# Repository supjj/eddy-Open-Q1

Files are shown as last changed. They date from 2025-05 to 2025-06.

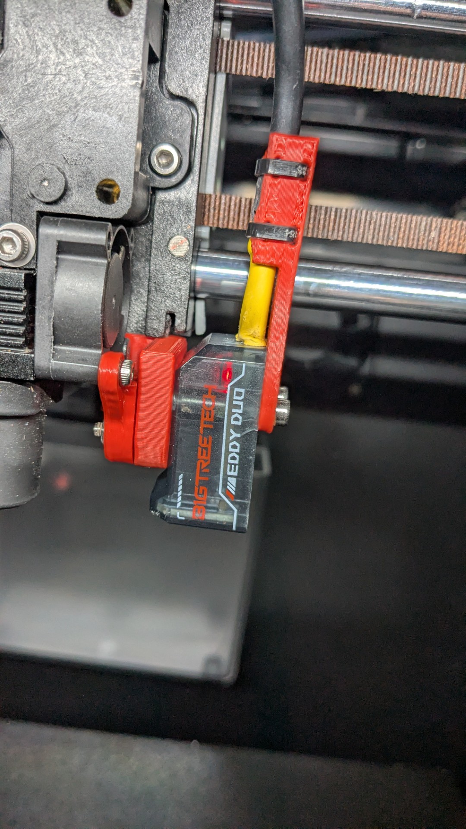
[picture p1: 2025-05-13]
eddy_mount/images/q1_pro_eddy_easyalign4 (Large).jpg

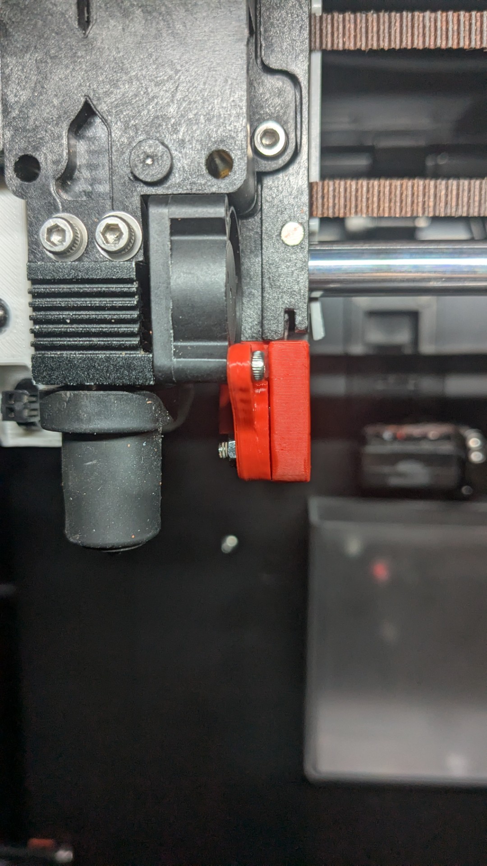
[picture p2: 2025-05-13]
eddy_mount/images/q1_pro_eddy_easyalign3 (Large).jpg

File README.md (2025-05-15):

# eddy-Open-Q1
eddy/eddy-ng configurations for Qidi Open Q1 Pro

Goal: to ease friction when swapping eddy and eddy-ng probe configurations

For use with

https://github.com/frap129/OpenQ1

Additional reference

https://github.com/bigtreetech/Eddy

https://github.com/vvuk/eddy-ng

https://github.com/straga/3d_printer

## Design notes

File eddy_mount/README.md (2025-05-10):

WARNING! It is vital that the 18mm screws that come with the Big Tree Tech Eddy are used with this mount. Longer screws will bottom out (top out in this case) and cause carriage assembly issues when tightened.

Configuration files will need to be tweaked depending on the model that is printed. The configs in this repo are made for the 2mm inset model I am using.

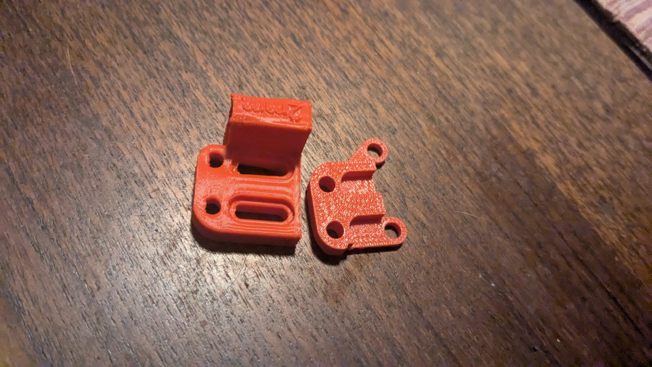
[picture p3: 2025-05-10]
eddy_mount/images/q1_eddy_stable1 (Large).jpg

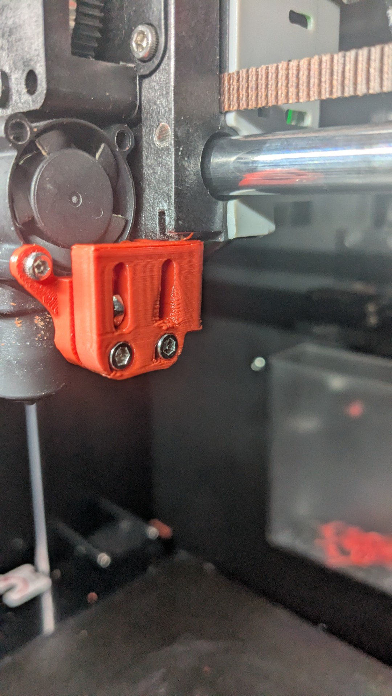
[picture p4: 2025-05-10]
eddy_mount/images/q1_eddy_stable2 (Large).jpg

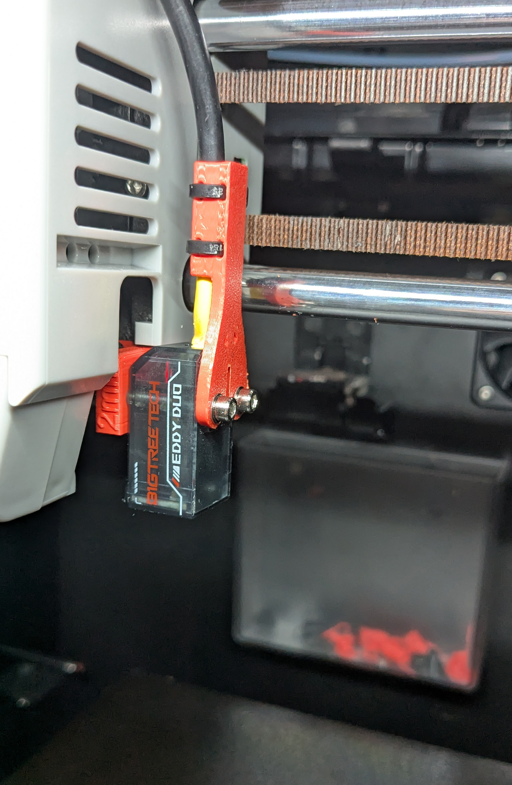
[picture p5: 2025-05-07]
eddy_mount/images/btt_eddy_strain_relief.jpg

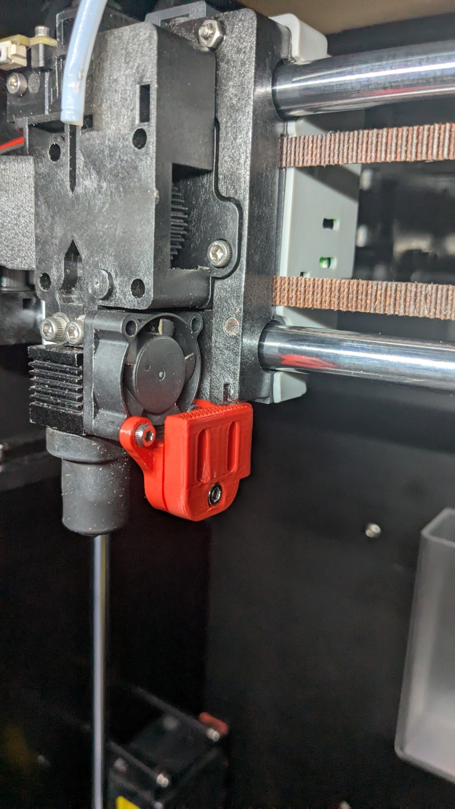
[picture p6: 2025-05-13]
eddy_mount/images/q1_pro_eddy_easyalign2 (Large).jpg

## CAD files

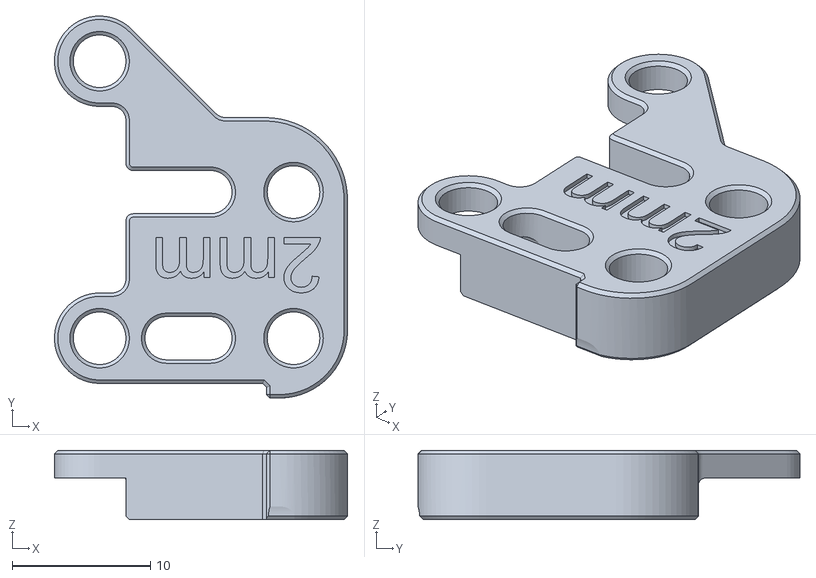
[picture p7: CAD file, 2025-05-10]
eddy_mount/stable_eddy/stl/2mm_full_inset_plate.stl
21.2 x 27.6 x 5.00

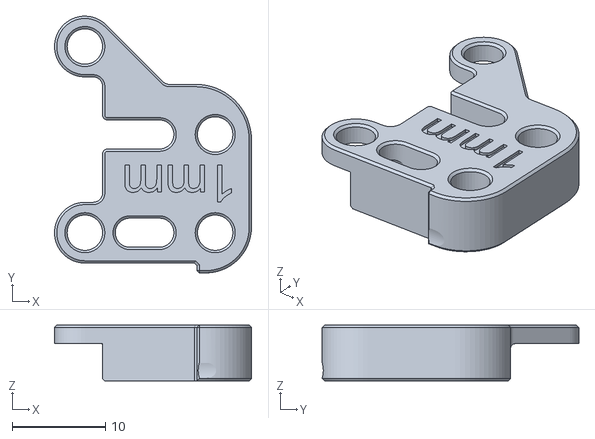
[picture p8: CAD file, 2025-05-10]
eddy_mount/stable_eddy/stl/1mm_full_inset_plate.stl
21.2 x 27.6 x 6.00

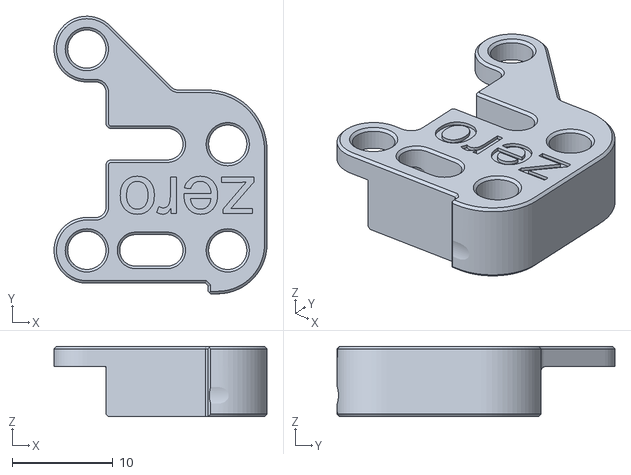
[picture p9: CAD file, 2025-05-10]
eddy_mount/stable_eddy/stl/zero_full_inset_plate.stl
21.2 x 27.6 x 7.00

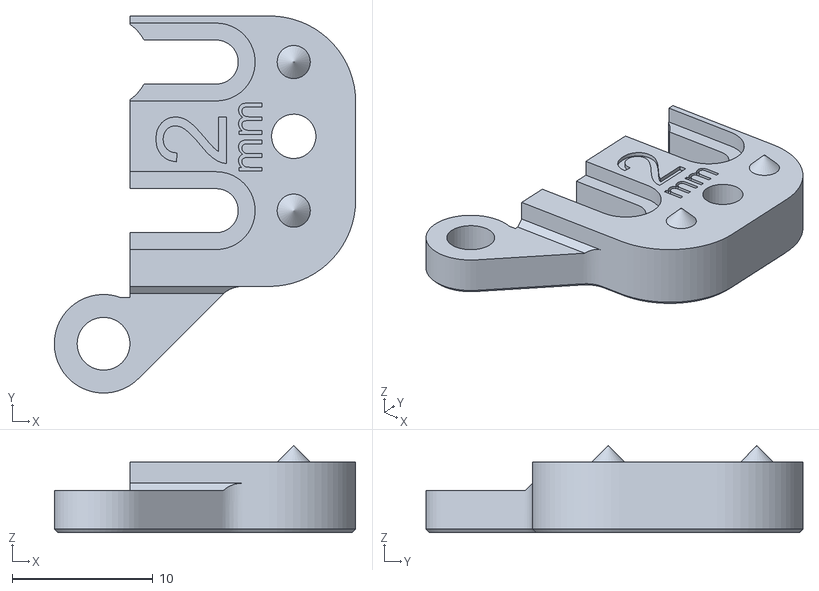
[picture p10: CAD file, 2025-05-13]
eddy_mount/easy_align_stable/2mm_inset_fan_mount.stl
21.4 x 26.8 x 6.18

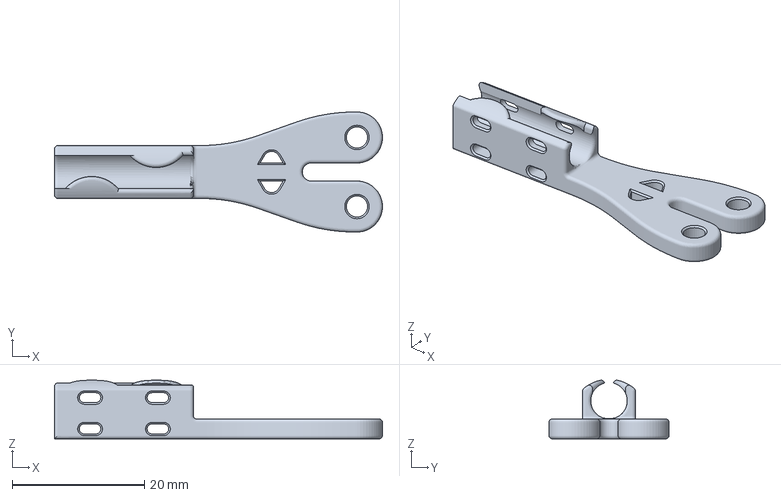
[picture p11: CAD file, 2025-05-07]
eddy_mount/eddy/btt_eddy_strain_relief.3mf
49.6 x 18.1 x 8.87 mm

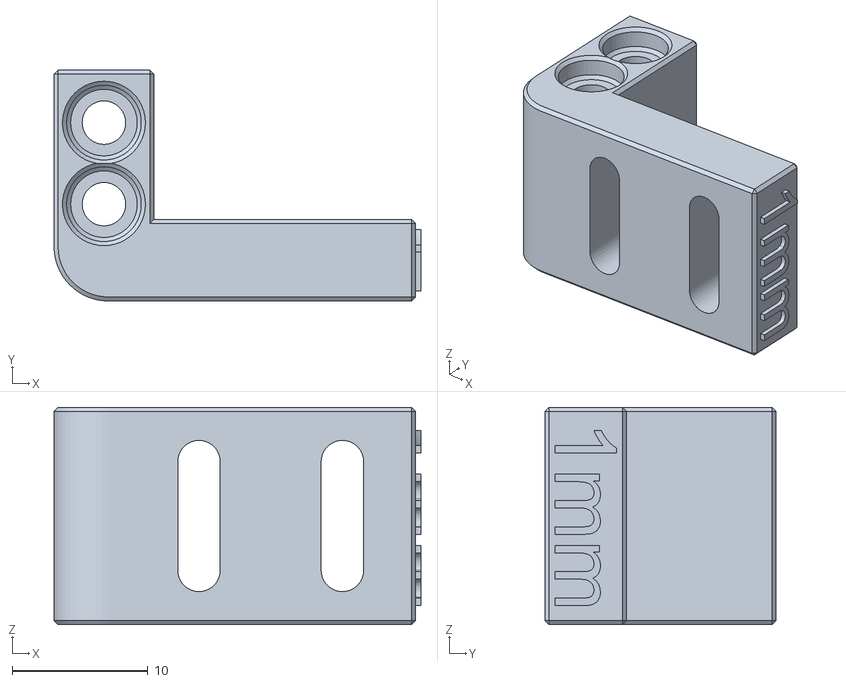
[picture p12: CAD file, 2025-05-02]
eddy_mount/eddy/stl/1mm_inset.stl
27.0 x 17.0 x 16.0

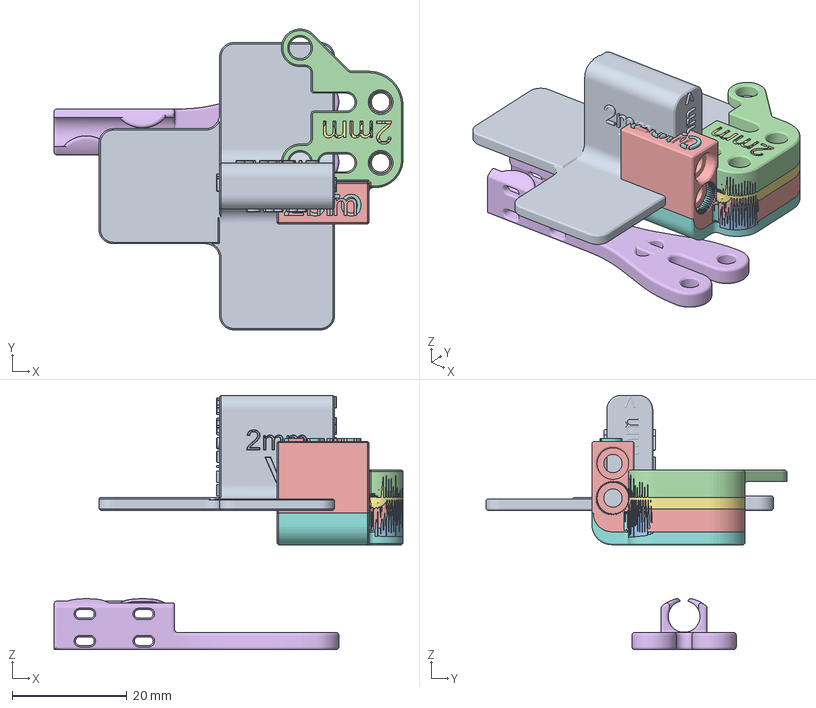
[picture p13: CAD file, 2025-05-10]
eddy_mount/stable_eddy/Q1_Pro_btt_eddy_mount v160.3mf
60.7 x 52.3 x 44.2 mm
calibration_block_20mm
1mm_full_inset_plate
1mm_inset
2mm_full_inset_plate
2mm_inset
strain_relief_stub
zero_full_inset_plate
zero_inset

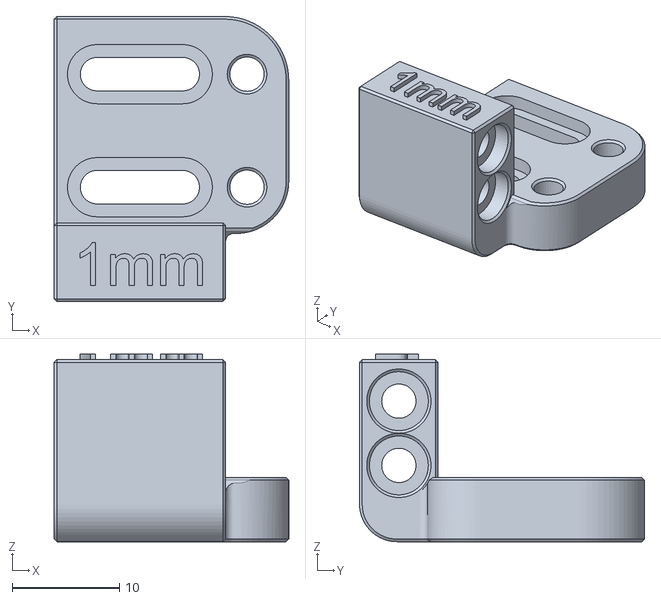
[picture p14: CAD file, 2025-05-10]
eddy_mount/stable_eddy/stl/1mm_inset.stl
21.9 x 26.6 x 17.5

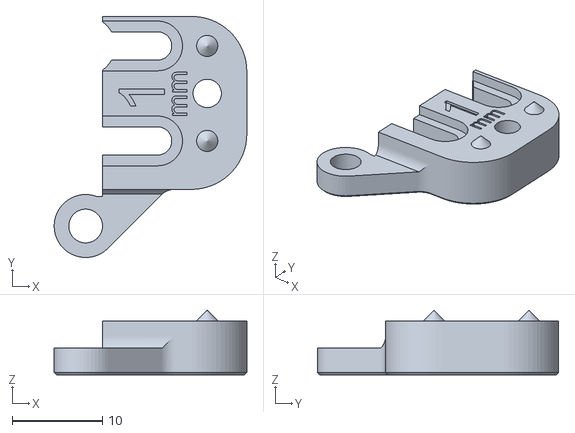
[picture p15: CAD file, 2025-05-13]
eddy_mount/easy_align_stable/1mm_inset_fan_mount.stl
21.4 x 26.8 x 7.18

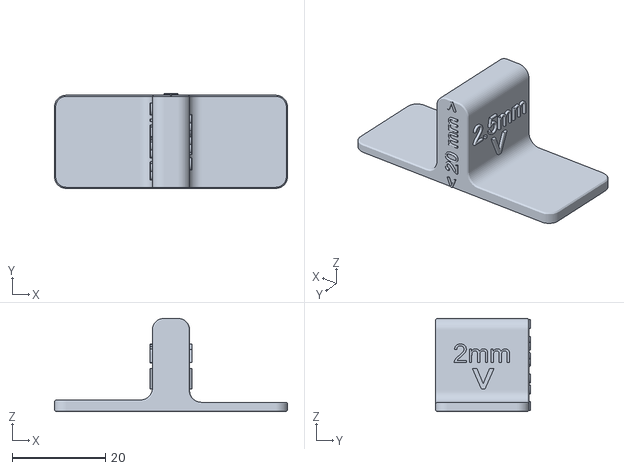
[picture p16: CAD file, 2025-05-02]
eddy_mount/eddy/stl/calibration_block_2mm_20mm_2.5mm.stl
50.0 x 20.3 x 20.0

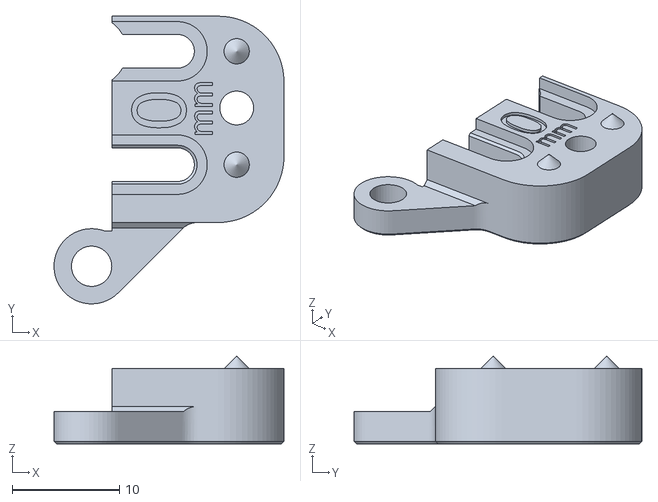
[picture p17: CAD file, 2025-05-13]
eddy_mount/easy_align_stable/zero_inset_fan_mount.stl
21.4 x 26.8 x 8.18

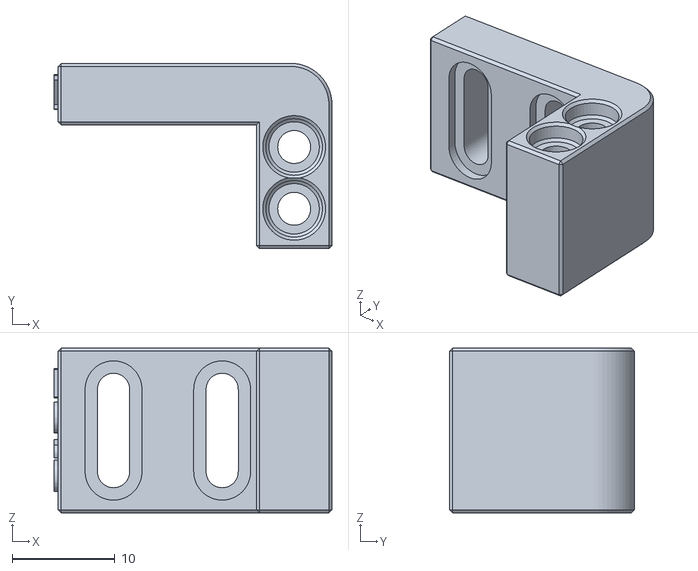
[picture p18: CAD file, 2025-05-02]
eddy_mount/eddy/stl/zero.stl
27.0 x 18.0 x 16.0

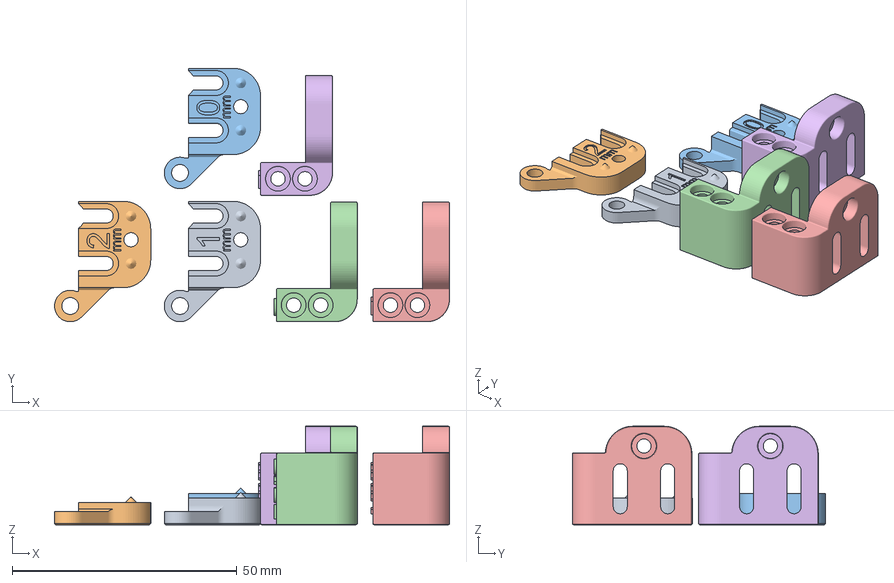
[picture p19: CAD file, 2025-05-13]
eddy_mount/easy_align_stable/Q1_Pro_btt_easy_align_stable.3mf
87.8 x 56.3 x 21.9 mm
1mm_inset x 2
2mm_inset x 2
zero_inset x 2

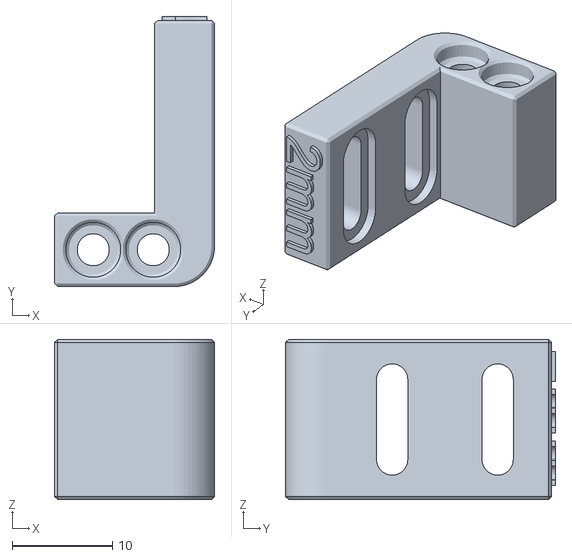
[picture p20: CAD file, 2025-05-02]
eddy_mount/eddy/stl/2mm_inset.stl
16.0 x 27.0 x 16.0

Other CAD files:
eddy_mount/stable_eddy/stl/strain_relief_stub.stl
eddy_mount/easy_align_stable/zero_inset_base.stl
eddy_mount/stable_eddy/stl/2mm_inset.stl
eddy_mount/easy_align_stable/2mm_inset_base.stl
eddy_mount/easy_align_stable/1mm_inser_base.stl
eddy_mount/eddy/Q1_Pro_btt_eddy_18mm_screws.3mf
eddy_mount/eddy/stl/btt_eddy_strain relief.stl
eddy_mount/stable_eddy/stl/ calibration_block_20mm.stl
eddy_mount/stable_eddy/stl/zero_inset.stl

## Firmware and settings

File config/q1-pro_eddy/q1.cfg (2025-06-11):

## DO NOT EDIT THIS FILE.
# This file is part of a git repository, your changes may prevent updates

[mcu]
serial: /dev/ttyS2
restart_method: command

[mcu U_1]
serial: /dev/ttyS0
restart_method: command

[respond]
default_type: echo

[resonance_tester]
accel_per_hz: 150
max_smoothing:0.5

[duplicate_pin_override]
pins:
     gpio21 ,U_1:PC3

[force_move]
enable_force_move : True

[bed_screws]
screw1:10,10
screw1_name: Front left
screw2: 230,10
screw2_name: Front right
screw3: 125,240
screw3_name: Back right
probe_height: 0.2
horizontal_move_z: 10

#[screws_tilt_adjust]
# screw1:10,10
# screw1_name: Front left
# screw2: 220,10
# screw2_name: Front right
# screw3: 125,230
# screw3_name: Back right
# screw_thread: CW-M4

[screws_tilt_adjust]
screw1:0,17
screw1_name: Front left
screw2: 196,17
screw2_name: Front right
screw3: 91,230
screw3_name: Back right
screw_thread: CW-M4 

[hall_filament_width_sensor]
adc1: gpio27
adc2: gpio28
cal_dia1: 1.48 # calibration data from author's unit
cal_dia2: 1.97 # this hall effect filament sensor is kinda useless as width sensor actually,
raw_dia1: 13422 # because the inlet is not mounted rigidly, the filament will pivot and make the reading really high when bend to the left
raw_dia2: 14765
default_nominal_filament_diameter: 1.75
max_difference: 0
measurement_delay: 102
enable: false
measurement_interval: 10
logging: False
min_diameter: 1.0
max_diameter: 2.7
use_current_dia_while_delay: False
pause_on_runout: True
runout_gcode:
            PAUSE
            RESET_FILAMENT_WIDTH_SENSOR
            M118 Filament run out
event_delay: 3.0
pause_delay: 0.5

[extruder]
step_pin:gpio5
dir_pin:gpio4
enable_pin:!gpio10
rotation_distance: 53.7  #22.6789511    #Bondtech 5mm Drive Gears
gear_ratio: 1517:170
microsteps: 16
full_steps_per_rotation: 200    #200 for 1.8 degree, 400 for 0.9 degree
nozzle_diameter: 0.400
filament_diameter: 1.75
min_temp: 0
max_temp: 360
min_extrude_temp: 175
smooth_time: 0.000001
heater_pin:gpio24
sensor_type:MAX6675
sensor_pin:gpio17
spi_software_sclk_pin:gpio18
spi_software_mosi_pin:gpio19
spi_software_miso_pin:gpio16
spi_speed: 100000
max_power: 1
control : pid
pid_Kp=33.555
pid_Ki=4.76
pid_Kd=59.141
pressure_advance: 0.032
pressure_advance_smooth_time: 0.03
max_extrude_cross_section:500
instantaneous_corner_velocity: 10.000
max_extrude_only_distance: 1000.0
max_extrude_only_velocity:5000
max_extrude_only_accel:2000
step_pulse_duration:0.000002

[tmc2209 extruder]
uart_pin:gpio6
interpolate: True
run_current: 0.714
stealthchop_threshold: 0

[adxl345]
cs_pin:gpio13
spi_software_sclk_pin:gpio14
spi_software_mosi_pin:gpio15
spi_software_miso_pin:gpio12
axes_map: -x, z, -y

[printer]
kinematics:corexy
max_velocity: 600
max_accel: 20000
max_z_velocity: 10
max_z_accel: 500
square_corner_velocity: 8

[stepper_x]
step_pin:U_1:PB4
dir_pin:!U_1:PB3
enable_pin:!U_1:PB5
microsteps:16
rotation_distance: 39.88
full_steps_per_rotation:200  #set to 400 for 0.9 degree stepper
endstop_pin:tmc2240_stepper_x:virtual_endstop
position_min: -5.5
position_endstop: -5.5
position_max:245
homing_speed:50
homing_retract_dist:0
homing_positive_dir:False
step_pulse_duration:0.0000001

[stepper_y]
step_pin:U_1:PC14
dir_pin:!U_1:PC13
enable_pin:!U_1:PC15
microsteps: 16
rotation_distance: 39.88
full_steps_per_rotation:200  #set to 400 for 0.9 degree stepper
endstop_pin:tmc2240_stepper_y:virtual_endstop
position_min: -4.5
position_endstop: -4.5
position_max: 258
homing_speed:50
homing_retract_dist:0
homing_positive_dir:False
step_pulse_duration:0.0000001

[stepper_z]
step_pin:U_1:PC10
dir_pin:U_1:PA15
enable_pin:!U_1:PC11
microsteps: 128
rotation_distance: 4
full_steps_per_rotation: 200
endstop_pin: probe:z_virtual_endstop #eddy endstop
position_max: 248
position_min: -4
homing_speed: 8
second_homing_speed: 10
homing_retract_dist: 5.0
homing_positive_dir:false

[stepper_z1]
step_pin:U_1:PB1
dir_pin:U_1:PB6
enable_pin:!U_1:PB0
microsteps: 128
rotation_distance: 4
full_steps_per_rotation: 200
step_pulse_duration:0.0000001

[z_tilt]
z_positions:
    -59,125
    306,125

points:
    0, 118 # 0-34=eddy x (0) , 125-7=eddy y (118) 
    196, 118 # 245-34=eddy x (191) , 125-7=eddy y (118)

speed: 150
horizontal_move_z: 5
retries: 3
retry_tolerance: 0.05

# [z_tilt]
# z_positions:
#     -59,125
#    307.5,125
# 
# points:
#     0,125
#     215,125
# 
# speed: 150
# horizontal_move_z: 5
# retries: 2
# retry_tolerance: 0.05

[tmc2240 stepper_y]
cs_pin: U_1:PB9
spi_software_sclk_pin: U_1:PA5
spi_software_mosi_pin: U_1:PA7
spi_software_miso_pin: U_1:PA6
spi_speed: 200000
run_current: 1.07
interpolate: true
stealthchop_threshold: 0
coolstep_threshold: 15
diag0_pin: !U_1:PC0
driver_SGT: 1

[tmc2240 stepper_x]
cs_pin: U_1:PD2
spi_software_sclk_pin: U_1:PA5
spi_software_mosi_pin: U_1:PA7
spi_software_miso_pin: U_1:PA6
spi_speed: 200000
run_current: 1.07
interpolate: true
stealthchop_threshold: 0
coolstep_threshold: 15
diag0_pin: !U_1:PB8
driver_SGT: 1

[tmc2209 stepper_z]
uart_pin:U_1: PC5
run_current: 0.6
interpolate: True
stealthchop_threshold: 9999999999

[tmc2209 stepper_z1]
uart_pin:U_1: PB7
run_current: 0.6
interpolate: True
stealthchop_threshold: 9999999999

[heater_bed]
heater_pin: U_1:PB10
sensor_type:NTC 100K MGB18-104F39050L32
sensor_pin:U_1: PA0
max_power: 1.0
control = pid
pid_Kp=63.418
pid_Ki=1.342
pid_Kd=749.125
min_temp: -60
max_temp: 125

[heater_generic chamber]
heater_pin:U_1:PC8
max_power:1.0
sensor_type:NTC 100K MGB18-104F39050L32
sensor_pin:U_1:PA1
control = pid
#max_delta: 1.0
pid_Kp=63.418
pid_Ki=1.342
pid_Kd=749.125

min_temp:-100
max_temp:62

[verify_heater chamber]
max_error: 300
check_gain_time:480
hysteresis: 5
heating_gain: 1

[verify_heater extruder]
max_error: 120
check_gain_time:20
hysteresis: 5
heating_gain: 1

[verify_heater heater_bed]
max_error: 200
check_gain_time:60
hysteresis: 5
heating_gain: 1

[fan_generic auxiliary_cooling_fan]
pin: U_1:PA8
shutdown_speed: 0.0
cycle_time: 0.0100
hardware_pwm: false
kick_start_time: 0.100
off_below: 0.0

[fan_generic chamber_circulation_fan]
pin:U_1:PC9
shutdown_speed: 0.0
cycle_time: 0.100
hardware_pwm: false
kick_start_time: 0.100
off_below: 0.0

[heater_fan chamber_fan]
pin:U_1:PA4
max_power: 1.0
shutdown_speed: 0
kick_start_time: 0.5
heater: chamber
heater_temp: 35
fan_speed: 1.0
off_below: 0

[heater_fan hotend_fan]
pin:gpio25
max_power: 1.0
shutdown_speed:1.0
kick_start_time: 0.5
heater: extruder
heater_temp: 65.0
fan_speed: 1.0
off_below: 0

[heater_fan hotend_fan2]
pin:gpio11
max_power: 1.0
shutdown_speed:1.0
kick_start_time: 0.5
heater: extruder
heater_temp: 65.0
fan_speed: 1.0
off_below: 0

[fan_generic cooling_fan]
pin:gpio2
max_power: 1.0
shutdown_speed: 0
cycle_time: 0.0100
hardware_pwm: false
kick_start_time: 0.100
off_below: 0.0

[temperature_sensor host]
sensor_type: temperature_host

[temperature_sensor toolhead_board_mcu]
sensor_type: temperature_mcu

[temperature_sensor mainboard_mcu]
sensor_type: temperature_mcu
sensor_mcu: U_1

[fan_generic board_fan]
pin:U_1:PC4
max_power:1.0
shutdown_speed:1.0

[delayed_gcode board_fan_control]
;description: 2-point linear fan curve control with hysteresis at the off/min state, basically default "watermark" control, but can go to 100% when printed in a heated chamber and extra cooling is needed, or just bang-bang with 20% when idle.
initial_duration: 1.
gcode:
    {% set t_off = 60 %} ; fan will turn off after dropping below this temperature at min_speed
    {% set t_on = 70 %} ; fan will turn on at "min_speed" after rising above this temperature
    {% set t_max = 80 %} ; fan is max at this temperature
    {% set t_tmcmax = 100.0 %} ; fan is max at this tmc2240 temperature
    {% set min_speed = 0.2 %} ; if fan speed should be between 0 and min_speed, min_speed will be used

    {% set temp_x = printer['tmc2240 stepper_x'].temperature|default(0)|float %}
    {% set temp_y = printer['tmc2240 stepper_y'].temperature|default(0)|float %}
    {% set temp_host = printer['temperature_sensor host'].temperature|default(0)|float %}
    {% set temp_mcu = printer['temperature_sensor mainboard_mcu'].temperature|default(0)|float %}
    {% set max_temp = ([temp_host, temp_mcu, temp_x / t_tmcmax * t_max, temp_y / t_tmcmax * t_max] | sort)[-1] %}
    ; max detected temperature on the electronics bay

    {% if ( max_temp >= t_on ) %}
        {% set fan_speed = ([( [max_temp - t_on, t_max - t_on] | min), 0] | max) / (t_max - t_on) * (1.0 - min_speed) + min_speed %}
        {% if (fan_speed > 0) and (fan_speed < min_speed) %}
            {% set fan_speed = min_speed %}
        {% endif %}
        SET_FAN_SPEED FAN=board_fan SPEED={fan_speed}
    {% elif max_temp < t_off %}
        SET_FAN_SPEED FAN=board_fan SPEED=0
    {% elif printer['fan_generic board_fan'].speed > 0 %}
        SET_FAN_SPEED FAN=board_fan SPEED={min_speed}
    {% endif %}

    UPDATE_DELAYED_GCODE ID=board_fan_control DURATION=1
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

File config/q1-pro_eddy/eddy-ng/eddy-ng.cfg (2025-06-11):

# The MCU section only applies to the Eddy USB. For Eddy Coil you will use the MCU name of the toolboard that you connected the Eddy Coil to.
[mcu eddy]
serial: /dev/serial/by-id/usb-Klipper_rp2040_504450610841231C-if00 # This is the serial address of your eddy probe. This can be found by using the terminal of your klipper instance (typically through SSH) and using the command ```ls /dev/serial/by-id``` 
restart_method: command


[temperature_sensor btt_eddy_mcu]
sensor_type: temperature_mcu # Sets the type of sensor for Klipper to read
sensor_mcu: eddy # Sets the MCU of the eddy probe tempereature sensor
min_temp: 10 # Sets the minimum tempereature for eddys tempereature sensor to operate
max_temp: 100 # Sets the maximum tempereature for eddys tempereature sensor to operate

[temperature_sensor btt_eddy]
sensor_type: Generic 3950
sensor_pin: eddy:gpio26

#[probe_eddy_current btt_eddy]
[probe_eddy_ng btt_eddy]
sensor_type: ldc1612
#z_offset: 2.5
#i2c_address:
i2c_mcu: eddy  # This value is good for the Eddy USB but would need to be adjusted for the Eddy Coil according to the MCU you have used.
i2c_bus: i2c0f # This value is good for the Eddy USB but would need to be adjusted for the Eddy Coil according to the I2C bus you have used.
# Measure the offsets below using the method described here: https://www.klipper3d.org/Probe_Calibrate.html#calibrating-probe-x-and-y-offsets
# For a standard Voron stealthburner X carriage mount there should be no need to change the defaults below.
x_offset: 34
y_offset: 7
tap_target_z: -1.050
samples_per_second: 600 # 250 by default
tap_max_samples: 11 # defaault 5
tap_samples_stddev: .025 #default 0.010

# This section is only relevant for Eddy USB. Comment it out for Eddy Coil.
# [temperature_probe btt_eddy]
# sensor_type: Generic 3950
# sensor_pin: eddy:gpio26
# horizontal_move_z: 2

[bed_mesh]
horizontal_move_z: 2
speed: 200
# For the mesh dimensions below, the coordinates need to be reachable by the center of the probe. To calculate coordinates that will work, use the formula below:
# mesh x min = position_min_x + greater_of (15mm or x_offset) <--- in this term, only consider the x offset if it is positive, ignore if negative.
# mesh y min = position_min_y + greater_of (15mm or y_offset) <--- in this term, only consider the y offset if it is positive, ignore if negative.
# mesh x max = position_max_x - greater_of (15mm or |x_offset|) <--- in this term, only consider the x offset if it is negative, ignore if positive.
# mesh y max = position_max_y - greater_of (15mm or |y_offset|) <--- in this term, only consider the y offset if it is negative, ignore if positive.
# Example: Consider that you have a 300 x 300 bed with the max x and y positions being 300 and the min being 0. Your probe offsets are -20 for X and 10 for Y
# For mesh x min we ignore the x offset term because it is negative. Therefore mesh x min = 15
# For mesh y min we do not ignore the y offset term because it is positive but it is less than 15 so we use 15. Therefore mesh y min = 15
# For mesh x max we do not ignore the x offset term because it is negative. It is also greater than 15. Therefore mesh x max = 280
# For mesh y max we ignore the y offset term because it is positive but it is less than 15 so we use 15. Therefore mesh y max = 285
# The final result would be mesh_min: 15, 15 mesh_max: 280, 285
mesh_min: 34, 15   # 34>15 x=[34], 7<15 y=[15] # modify these according to the above guide. If the probe cannot reach then you will get a klipper error when trying to scan a bed mesh.
mesh_max: 211, 230 # 245>34 245-34 x=[211], 245>7 245-15 y=[230] # modify these according to the above guide. If the probe cannot reach then you will get a klipper error when trying to scan a bed mesh.
probe_count: 11, 11
algorithm: bicubic
#scan_overshoot: 2  #uncomment this section if you still have room left over on the X axis for some scan overshoot to product smoother movements and more accurate scanning. Uncommenting this should be fine if you are using a standard voron mount.

# Uncomment this if you are using Eddy as the probe AND the homing endstop
#[safe_z_home]
#home_xy_position: 120,120 #probe 91, 118  Choose an X,Y position that is in the center of your bed. For a 300x300 machine that will be 150, 150. Use the same principle to calculate your bed center.
#z_hop: 10
#z_hop_speed: 25
#speed: 50
#move_to_previous: false

###############################Macros and related################################
#This secton contains macros and related config sections. Some should be used, others are optional. Read the comment above each one to find out whether or not to uncomment it for your installation.


# Uncomment this if you are using Eddy as the probe AND the homing endstop AND would like to use the beta z-offset control
[save_variables]
filename: ~/printer_data/config/variables.cfg



# Uncomment this if you are using Eddy as the probe AND the homing endstop
[force_move]
enable_force_move: True # Allows a user to move the z axis down if they have no other means of homing Z and need to calibrate the Eddy.



# Uncomment this if you are using Eddy as the probe AND the homing endstop AND would like to use the beta z-offset control
[delayed_gcode RESTORE_PROBE_OFFSET]
initial_duration: 1.
gcode:
  {% set svv = printer.save_variables.variables %}
  {% if not printer["gcode_macro SET_GCODE_OFFSET"].restored %}
    SET_GCODE_VARIABLE MACRO=SET_GCODE_OFFSET VARIABLE=runtime_offset VALUE={ svv.nvm_offset|default(0) }
    SET_GCODE_VARIABLE MACRO=SET_GCODE_OFFSET VARIABLE=restored VALUE=True
  {% endif %}



# Uncomment this if you are using Eddy as the probe AND the homing endstop
# Take note of the lines that should only be used if you have a KNOMI installed.
# [gcode_macro G28]
# rename_existing: G28.1
# gcode:
#  #SET_GCODE_VARIABLE MACRO=_KNOMI_STATUS VARIABLE=homing VALUE=True # Uncomment this if using a KNOMI and then remove the G28 macro from the KNOMI.cfg
#  G28.1 {rawparams}
#  {% if not rawparams or (rawparams and 'Z' in rawparams) %}
#    PROBE
#    SET_Z_FROM_PROBE
#  {% endif %}
#  #SET_GCODE_VARIABLE MACRO=_KNOMI_STATUS VARIABLE=homing VALUE=False # Uncomment this if using a KNOMI and then remove the G28 macro from the KNOMI.cfg



# Uncomment this if you are using Eddy as the probe AND the homing endstop
[gcode_macro SET_Z_FROM_PROBE]
gcode:
    {% set cf = printer.configfile.settings %}
    SET_GCODE_OFFSET_ORIG Z={printer.probe.last_z_result - cf['probe_eddy_current btt_eddy'].z_offset + printer["gcode_macro SET_GCODE_OFFSET"].runtime_offset}
    G90
    G1 Z{cf.safe_z_home.z_hop}


# Uncomment this if you are using Eddy as the probe AND the homing endstop AND would like to use the beta z-offset control
[gcode_macro Z_OFFSET_APPLY_PROBE]
rename_existing: Z_OFFSET_APPLY_PROBE_ORIG
gcode:
  SAVE_VARIABLE VARIABLE=nvm_offset VALUE={ printer["gcode_macro SET_GCODE_OFFSET"].runtime_offset }



# Uncomment the lines in this macro if you are using Eddy as the probe AND the homing endstop AND would like to use the beta z-offset control
[gcode_macro SET_GCODE_OFFSET]
rename_existing: SET_GCODE_OFFSET_ORIG
variable_restored: False  # Mark whether the var has been restored from NVM
variable_runtime_offset: 0
gcode:
  {% if params.Z_ADJUST %}
    SET_GCODE_VARIABLE MACRO=SET_GCODE_OFFSET VARIABLE=runtime_offset VALUE={ printer["gcode_macro SET_GCODE_OFFSET"].runtime_offset + params.Z_ADJUST|float }
  {% endif %}
  {% if params.Z %} 
    {% set paramList = rawparams.split() %}
    {% for i in range(paramList|length) %}
      {% if paramList[i]=="Z=0" %}
        {% set temp=paramList.pop(i) %}
        {% set temp="Z_ADJUST=" + (-printer["gcode_macro SET_GCODE_OFFSET"].runtime_offset)|string %}
        {% if paramList.append(temp) %}{% endif %}
      {% endif %}
    {% endfor %}
    {% set rawparams=paramList|join(' ') %}
    SET_GCODE_VARIABLE MACRO=SET_GCODE_OFFSET VARIABLE=runtime_offset VALUE=0
  {% endif %}
  SET_GCODE_OFFSET_ORIG { rawparams }



# This macro automates a lot of the frequency mapping process and simplifies the steps significantly.
[gcode_macro PROBE_EDDY_CURRENT_CALIBRATE_AUTO]
gcode:
  BED_MESH_CLEAR
  G90 # Abs positioning
  G1 X{ printer.toolhead.axis_maximum.x/2 } Y{ printer.toolhead.axis_maximum.y/2 } F6000
  {% if 'z' not in printer.toolhead.homed_axes %}
    SET_KINEMATIC_POSITION Z={ printer.toolhead.axis_maximum.z-1 } # Allows the user to work it down until it touches.
  {% endif %}
  PROBE_EDDY_CURRENT_CALIBRATE {rawparams}
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

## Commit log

2025-05-10 Rename eddy_mount/stl/btt_eddy_strain relief.stl to eddy_mount/eddy/stl/btt_eddy_strain relief.stl
    [btt_eddy_strain relief.stl]
2025-06-11 moved gcode macro
    moved gcode macro config files into dedicated homing override and z-safe folders and edited the cascade linked files
    [eddy-ng.cfg, eddy.cfg, gcode_macro.cfg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]
